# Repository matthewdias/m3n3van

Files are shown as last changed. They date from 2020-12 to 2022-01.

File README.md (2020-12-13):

# m3n3van
 
- The rev1 pcb supports a lot of different layouts. This was mostly an exercise for me and a way to make some unique bottom rows available that wouldn't exist otherwise. As a result it has a few issues, a missing switch, and lots of conflicts with screw holes, necessitating switch rotation.

- The rev2 pcb is a return to the original idea of simply a minivan with 2x3u split space.

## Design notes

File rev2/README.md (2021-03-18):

## Layout

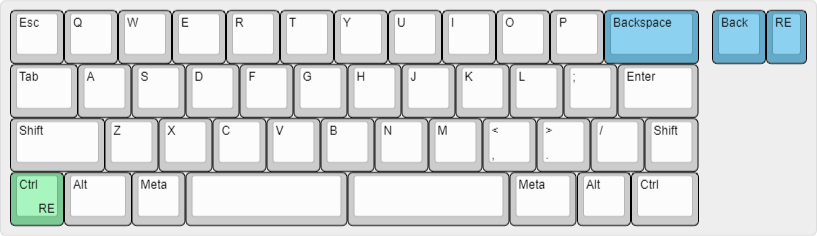
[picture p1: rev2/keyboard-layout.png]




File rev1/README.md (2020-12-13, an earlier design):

## Layout Options

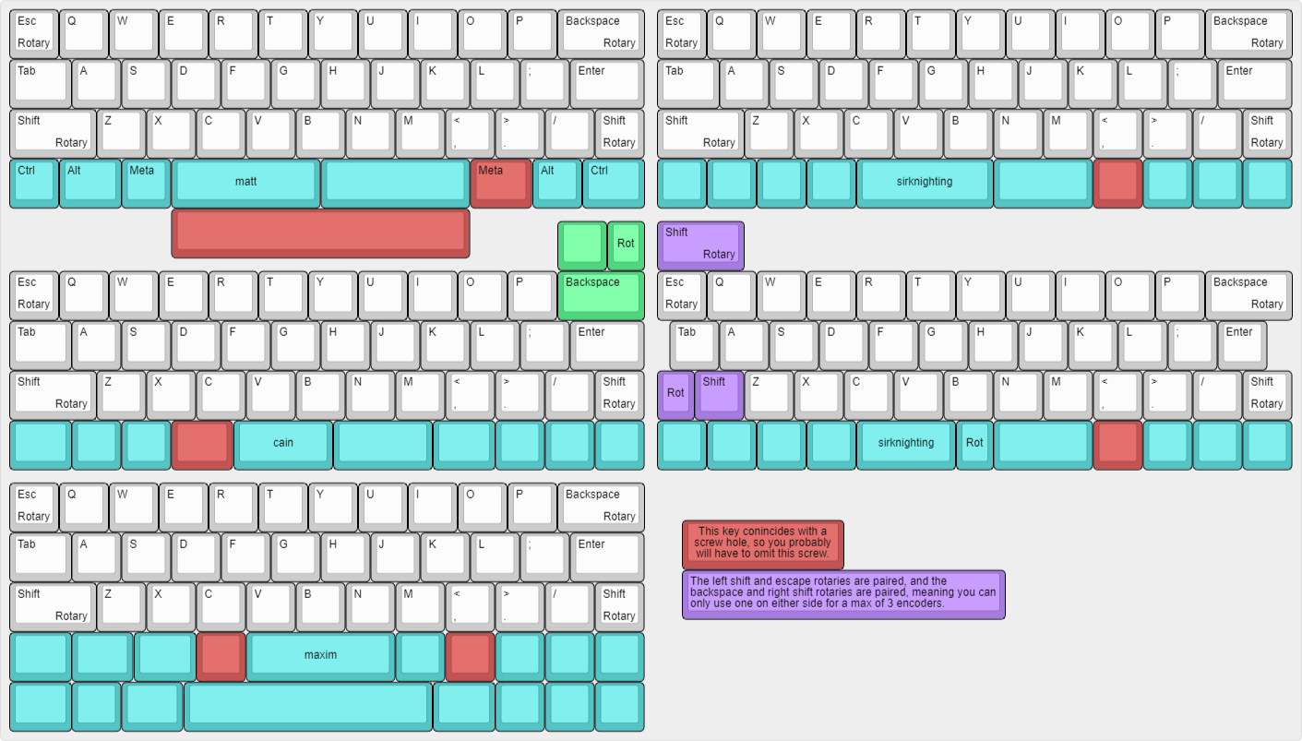
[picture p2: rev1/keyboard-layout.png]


Configure firmware at https://qmk.thevankeyboards.com/




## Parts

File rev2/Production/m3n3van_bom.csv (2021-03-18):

Designator | Quantity | Value | Footprint | LCSC Part #
C1, | 1 | 1uF | 0603 | C15849
C4, C3, C2, C5, C6, | 5 | 0.1uF | 0603 | C14663
C7, | 1 | 10uF | 0603 | C19702
D_1, D_2, D_3, D_4, D_5, D_6, D_7, D_8, D_9, D_10, D_11, D_12, D_13, D_14, D_15, D_16, D_17, D_18, D_19, D_20, D_21, D_22, D_23, D_24, D_25, D_26, D_27, D_28, D_29, D_30, D_31, D_32, D_33, D_34, D_35, D_36, D_37, D_38, D_39, D_40, D_41, D_42, D_43, D_44, D_45, | 45 | D | SOD-123 | C64898
F1, | 1 | 500mA | 1206 | C70076
R2, R3, | 2 | 5.1k | 0603 | C23186
R5, R4, | 2 | 22 | 0603 | C23345
R6, R1, | 2 | 10k | 0603 | C25804
SW1, | 1 | SW_Push | SMD | C561519
U1, | 1 | SRV05-4 | SOT-23-6 | C558454
U2, | 1 | AVR | 44-TQFP (10x10) | C44854
Y1, | 1 | 16MHz | SMD | C341521
USB1, | 1 | HRO-TYPE-C-31-M-12 | 8.94*7.3mm | C165948

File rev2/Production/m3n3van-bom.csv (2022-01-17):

Designator | Quantity | Value | Footprint | LCSC Part #
C1, | 1 | 1uF | 0603 | C15849
C2, C3, C4, C5, C6, | 5 | 0.1uF | 0603 | C14663
C7, | 1 | 10uF | 0603 | C19702
C8, C9, | 2 | 22pF | 0603 | C1653
D_1, D_2, D_3, D_4, D_5, D_6, D_7, D_8, D_9, D_10, D_11, D_12, D_13, D_14, D_15, D_16, D_17, D_18, D_19, D_20, D_21, D_22, D_23, D_24, D_25, D_26, D_27, D_28, D_29, D_30, D_31, D_32, D_33, D_34, D_35, D_36, D_37, D_38, D_39, D_40, D_41, D_42, D_43, D_44, D_45, | 45 | D | SOD-123 | C64898
F1, | 1 | 500mA | 1206 | C70076
R1, R6, | 2 | 10k | 0603 | C25804
R2, R3, | 2 | 5.1k | 0603 | C23186
R4, R5, | 2 | 22 | 0603 | C23345
SW1, | 1 | SW_Push | SMD | C561519
U1, | 1 | SRV05-4 | SOT-23-6 | C558454
U3, | 1 | ATmega32U4-MU | QFN-44 | C45874
USB1, | 1 | HRO-TYPE-C-31-M-12 | HRO-TYPE-C-31-M-12 | C165948
Y1, | 1 | 16MHz | 3225 | C13738

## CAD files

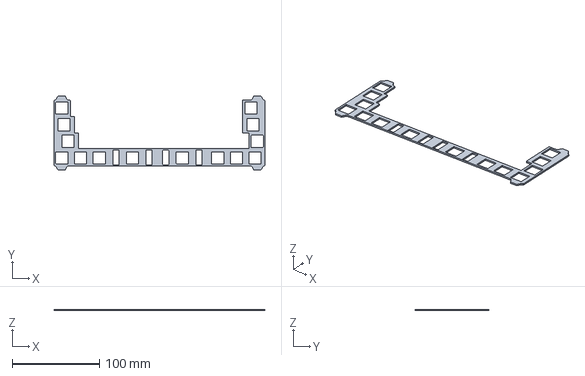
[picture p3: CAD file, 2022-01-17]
rev2/Plates/campsite/campsite-half.step
241.8 x 85.2 x 1.60 mm

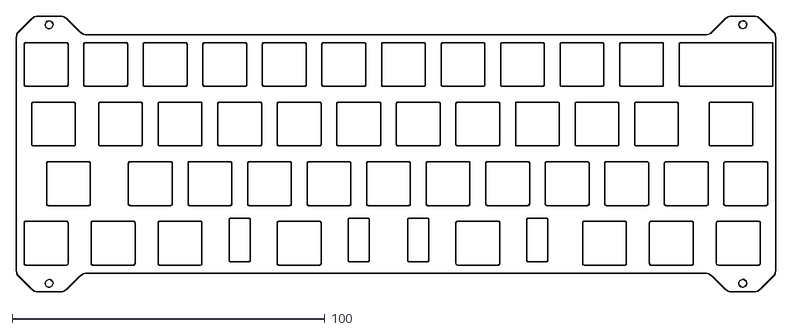
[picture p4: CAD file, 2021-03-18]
rev2/Plates/coriander/coriander.dxf
242.9 x 88.2

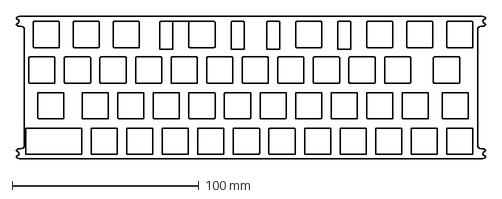
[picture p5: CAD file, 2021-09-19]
rev2/Plates/hull/hull.dxf
251.3 x 76.2 mm

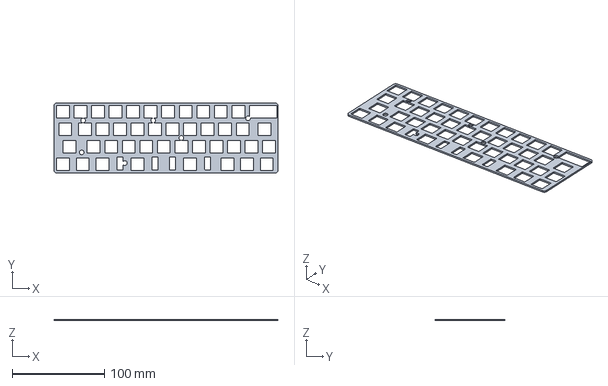
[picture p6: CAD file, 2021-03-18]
rev2/Plates/minivan/minivan.step
243.4 x 76.2 x 1.60 mm

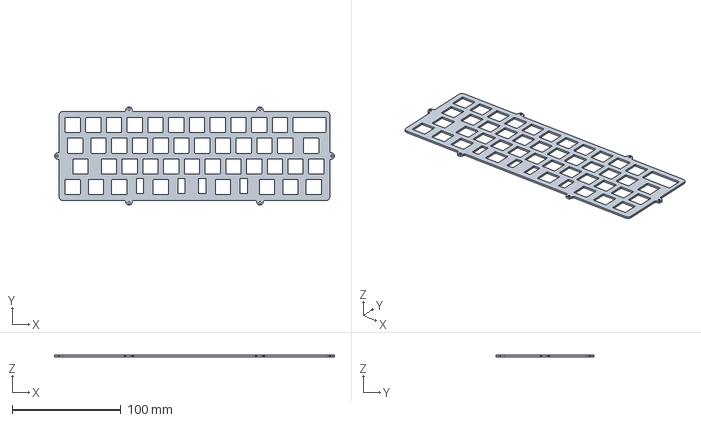
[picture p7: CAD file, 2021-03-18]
rev2/Plates/p3d-topmount/p3d-topmount.step
257.1 x 90.4 x 1.60 mm

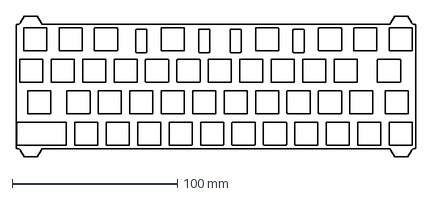
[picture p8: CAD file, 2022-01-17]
rev2/Plates/campsite/campsite-m3n3van.dxf
241.8 x 85.2 mm

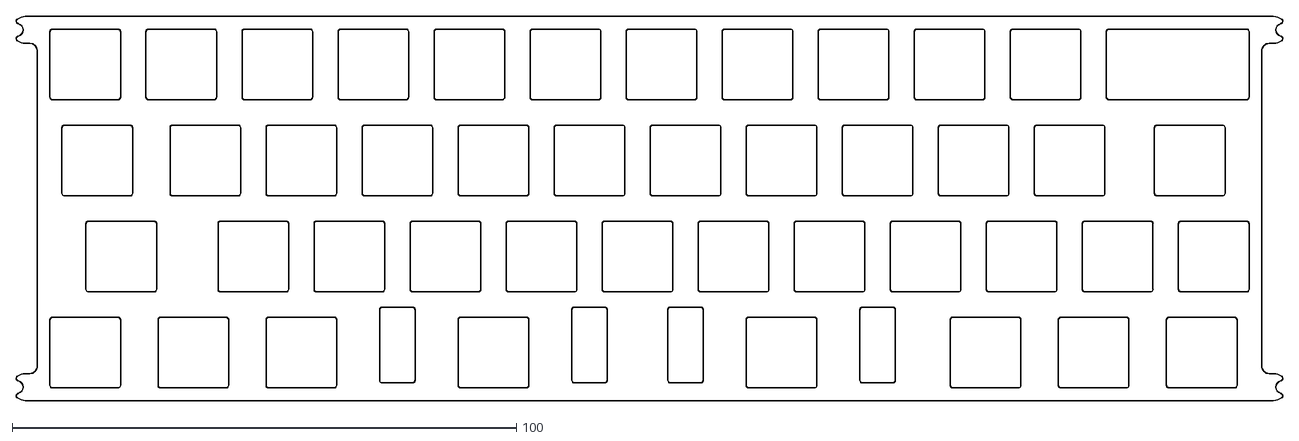
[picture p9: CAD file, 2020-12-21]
rev2/Plates/hull/hull-Edge_Cuts.dxf
251.3 x 76.2

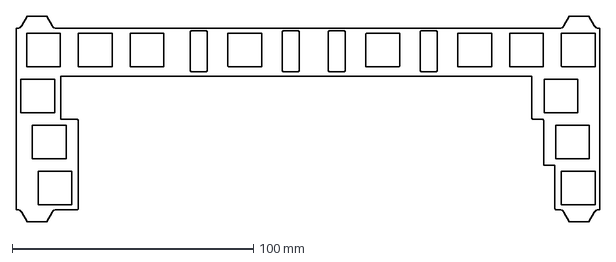
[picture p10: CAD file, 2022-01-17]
rev2/Plates/campsite/campsite-half-m3n3van.dxf
241.8 x 85.2 mm

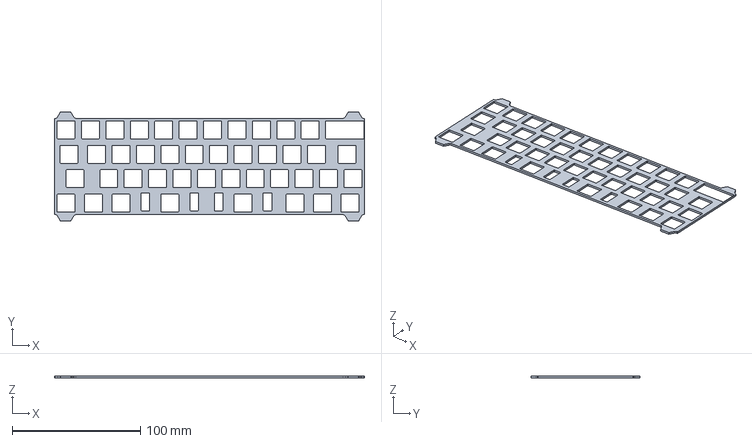
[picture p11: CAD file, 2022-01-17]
rev2/Plates/campsite/campsite.step
241.8 x 85.2 x 1.60 mm

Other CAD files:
rev2/Plates/minivan/minivan.dxf
rev2/Plates/p3d-topmount/p3d-topmount.dxf

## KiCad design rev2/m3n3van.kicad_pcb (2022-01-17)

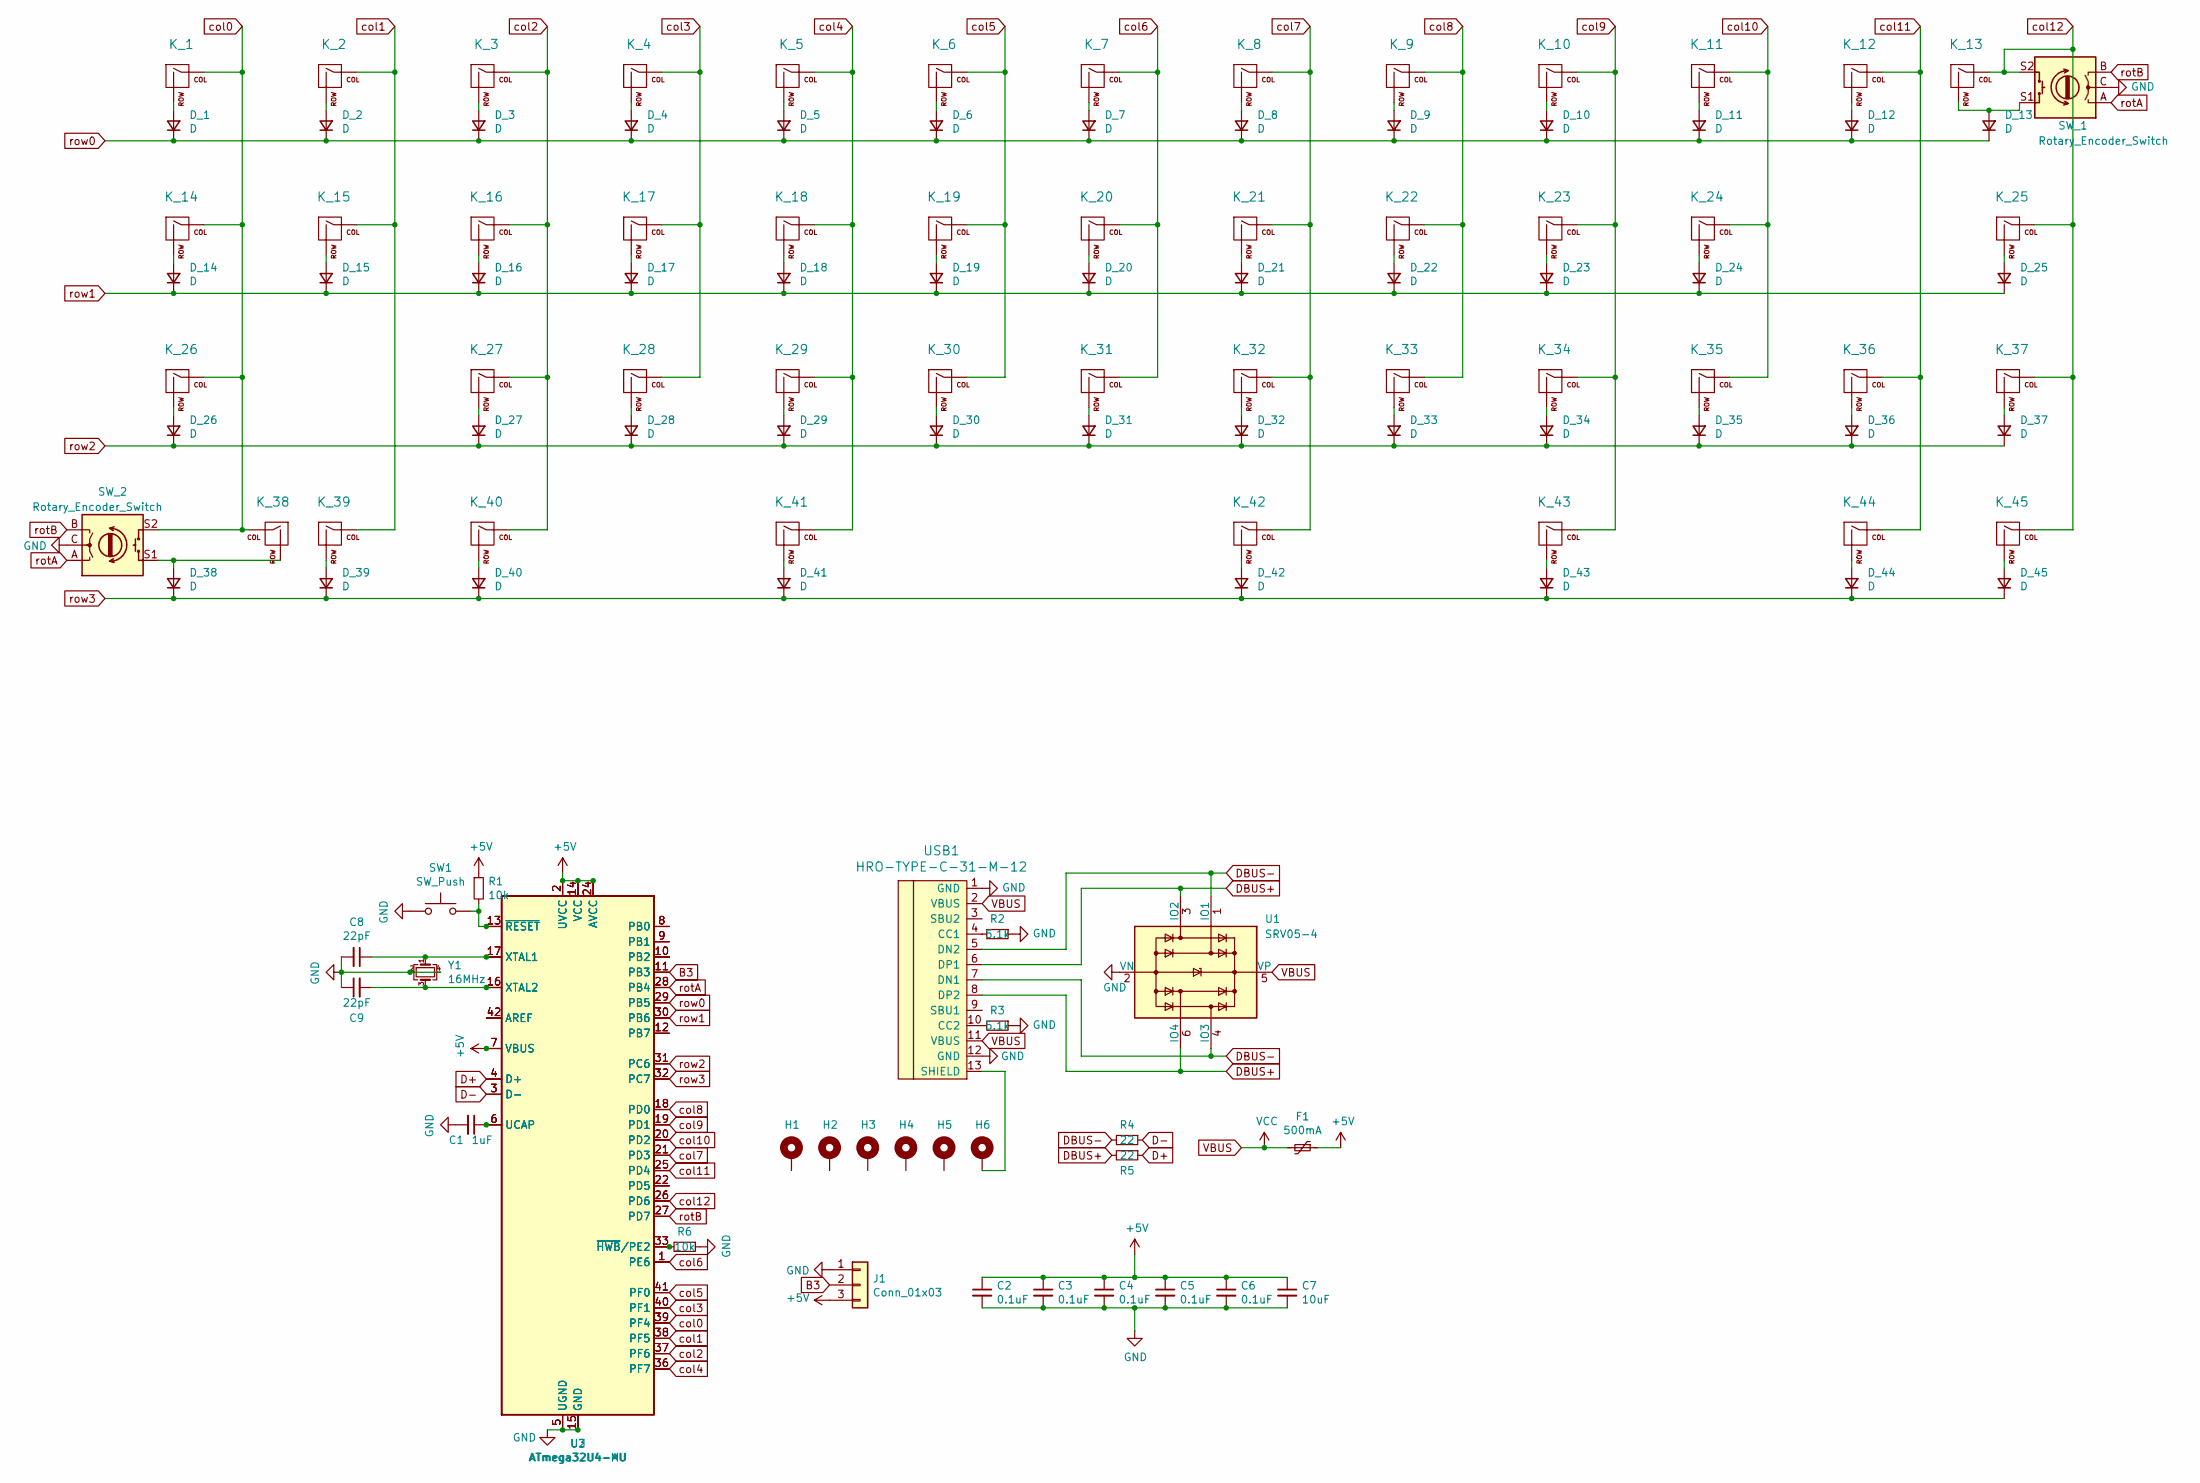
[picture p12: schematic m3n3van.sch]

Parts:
C1: 1uF; C_0603_1608Metric
C2, C3, C4, C5, C6: 0.1uF; C_0603_1608Metric
C7: 10uF; C_0603_1608Metric
C8, C9: 22pF; C_0603_1608Metric
D_1, D_2, D_3, D_4, D_5, D_6, D_7, D_8, D_9, D_10, D_11, D_12, D_13, D_14, D_15, D_16, D_17, D_18, D_19, D_20, D_21, D_22, D_23, D_24, D_25, D_26, D_27, D_28, D_29, D_30, D_31, D_32, D_33, D_34, D_35, D_36, D_37, D_38, D_39, D_40, D_41, D_42, D_43, D_44, D_45: D; D_SOD-123
F1: 500mA; Fuse_1206_3216Metric
H1, H2, H3, H4, H5, H6: MountingHole_Pad; MountingHole_2.2mm_M2_Pad
J1: Conn_01x03; PinHeader_1x03_P2.54mm_Vertical
K_1, K_2, K_3, K_4, K_5, K_6, K_7, K_8, K_9, K_10, K_11, K_12, K_15, K_16, K_17, K_18, K_19, K_20, K_21, K_22, K_23, K_24, K_27, K_28, K_29, K_30, K_31, K_32, K_33, K_34, K_35, K_36, K_37, K_38, K_40, K_44: KEYSW; MXOnly-1U-NoLED
K_13, K_26: KEYSW; MXOnly-1.75U-NoLED
K_14, K_39, K_43, K_45: KEYSW; MXOnly-1.25U-NoLED
K_25: KEYSW; MXOnly-1.5U-NoLED
K_41, K_42: KEYSW; MXOnly-3U-ReversedStabilizers-NoLED
R1, R6: 10k; R_0603_1608Metric
R2, R3: 5.1k; R_0603_1608Metric
R4, R5: 22; R_0603_1608Metric
SW1: SW_Push; SW_Push_SPST_NO_Alps_SKRK
SW_1, SW_2: Rotary_Encoder_Switch; RotaryEncoder_Alps_EC11E-Switch_Vertical_H20mm
U1: SRV05-4; SOT-23-6
U2: ATmega32U4-AU; TQFP-44_10x10mm_P0.8mm
U3: ATmega32U4-MU; QFN-44-1EP_7x7mm_P0.5mm_EP5.2x5.2mm
USB1: HRO-TYPE-C-31-M-12; HRO-TYPE-C-31-M-12-Assembly
Y1: 16MHz; Crystal_SMD_3225-4Pin_3.2x2.5mm

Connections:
+5V: C2.1, C3.1, C4.1, C5.1, C6.1, C7.1, F1.1, J1.3, R1.1, U2.2 (UVCC), U2.7 (VBUS), U2.14 (VCC), U2.24 (AVCC), U2.34 (VCC), U2.44 (AVCC), U3.2 (UVCC), U3.7 (VBUS), U3.14 (VCC), U3.24 (AVCC), U3.34 (VCC), U3.44 (AVCC)
B3: J1.2, U2.11 (PB3), U3.11 (PB3)
D+: R5.1, U2.4 (D+), U3.4 (D+)
D-: R4.1, U2.3 (D-), U3.3 (D-)
DBUS+: R5.2, U1.3 (IO2), U1.6 (IO4), USB1.6 (DP1), USB1.8 (DP2)
DBUS-: R4.2, U1.1 (IO1), U1.4 (IO3), USB1.5 (DN2), USB1.7 (DN1)
GND: C1.2, C2.2, C3.2, C4.2, C5.2, C6.2, C7.2, C8.2, C9.1, J1.1, R2.1, R3.1, R6.1, SW1.1, SW_1.C, SW_2.C, U1.2 (VN), U2.5 (UGND), U2.15 (GND), U2.23 (GND), U2.35 (GND), U2.43 (GND), U3.5 (UGND), U3.15 (GND), U3.23 (GND), U3.35 (GND), U3.43 (GND), U3.45 (GND), USB1.1 (GND), USB1.12 (GND), Y1.2, Y1.4
unnamed: C1.1, U2.6 (UCAP), U3.6 (UCAP)
unnamed: C8.1, U2.17 (XTAL1), U3.17 (XTAL1), Y1.1
unnamed: C9.2, U2.16 (XTAL2), U3.16 (XTAL2), Y1.3
unnamed: D_1.2 (A), K_1.2 (ROW)
unnamed: D_2.2 (A), K_2.2 (ROW)
unnamed: D_3.2 (A), K_3.2 (ROW)
unnamed: D_4.2 (A), K_4.2 (ROW)
unnamed: D_5.2 (A), K_5.2 (ROW)
unnamed: D_6.2 (A), K_6.2 (ROW)
unnamed: D_7.2 (A), K_7.2 (ROW)
unnamed: D_8.2 (A), K_8.2 (ROW)
unnamed: D_9.2 (A), K_9.2 (ROW)
unnamed: D_10.2 (A), K_10.2 (ROW)
unnamed: D_11.2 (A), K_11.2 (ROW)
unnamed: D_12.2 (A), K_12.2 (ROW)
unnamed: D_13.2 (A), K_13.2 (ROW), SW_1.S1
unnamed: D_14.2 (A), K_14.2 (ROW)
unnamed: D_15.2 (A), K_15.2 (ROW)
unnamed: D_16.2 (A), K_16.2 (ROW)
unnamed: D_17.2 (A), K_17.2 (ROW)
unnamed: D_18.2 (A), K_18.2 (ROW)
unnamed: D_19.2 (A), K_19.2 (ROW)
unnamed: D_20.2 (A), K_20.2 (ROW)
unnamed: D_21.2 (A), K_21.2 (ROW)
unnamed: D_22.2 (A), K_22.2 (ROW)
unnamed: D_23.2 (A), K_23.2 (ROW)
unnamed: D_24.2 (A), K_24.2 (ROW)
unnamed: D_25.2 (A), K_25.2 (ROW)
unnamed: D_26.2 (A), K_26.2 (ROW)
unnamed: D_27.2 (A), K_27.2 (ROW)
unnamed: D_28.2 (A), K_28.2 (ROW)
unnamed: D_29.2 (A), K_29.2 (ROW)
unnamed: D_30.2 (A), K_30.2 (ROW)
unnamed: D_31.2 (A), K_31.2 (ROW)
unnamed: D_32.2 (A), K_32.2 (ROW)
unnamed: D_33.2 (A), K_33.2 (ROW)
unnamed: D_34.2 (A), K_34.2 (ROW)
unnamed: D_35.2 (A), K_35.2 (ROW)
unnamed: D_36.2 (A), K_36.2 (ROW)
unnamed: D_37.2 (A), K_37.2 (ROW)
unnamed: D_38.2 (A), K_38.2 (ROW), SW_2.S1
unnamed: D_39.2 (A), K_39.2 (ROW)
unnamed: D_40.2 (A), K_40.2 (ROW)
unnamed: D_41.2 (A), K_41.2 (ROW)
unnamed: D_42.2 (A), K_42.2 (ROW)
unnamed: D_43.2 (A), K_43.2 (ROW)
unnamed: D_44.2 (A), K_44.2 (ROW)
unnamed: D_45.2 (A), K_45.2 (ROW)
unnamed: H6.1, USB1.13 (SHIELD)
unnamed: R1.2, SW1.2, U2.13 (~RESET), U3.13 (~RESET)
unnamed: R2.2, USB1.4 (CC1)
unnamed: R3.2, USB1.10 (CC2)
unnamed: R6.2, U2.33 (~HWB~/PE2), U3.33 (~HWB~/PE2)
unnamed: U2.8 (PB0), U3.8 (PB0)
unnamed: U2.9 (PB1), U3.9 (PB1)
unnamed: U2.10 (PB2), U3.10 (PB2)
unnamed: U2.12 (PB7), U3.12 (PB7)
unnamed: U2.22 (PD5), U3.22 (PD5)
unnamed: U2.42 (AREF), U3.42 (AREF)
VBUS: F1.2, U1.5 (VP), USB1.2 (VBUS), USB1.11 (VBUS)
col0: K_1.1 (COL), K_14.1 (COL), K_26.1 (COL), K_38.1 (COL), SW_2.S2, U2.39 (PF4), U3.39 (PF4)
col1: K_2.1 (COL), K_15.1 (COL), K_39.1 (COL), U2.38 (PF5), U3.38 (PF5)
col2: K_3.1 (COL), K_16.1 (COL), K_27.1 (COL), K_40.1 (COL), U2.37 (PF6), U3.37 (PF6)
col3: K_4.1 (COL), K_17.1 (COL), K_28.1 (COL), U2.40 (PF1), U3.40 (PF1)
col4: K_5.1 (COL), K_18.1 (COL), K_29.1 (COL), K_41.1 (COL), U2.36 (PF7), U3.36 (PF7)
col5: K_6.1 (COL), K_19.1 (COL), K_30.1 (COL), U2.41 (PF0), U3.41 (PF0)
col6: K_7.1 (COL), K_20.1 (COL), K_31.1 (COL), U2.1 (PE6), U3.1 (PE6)
col7: K_8.1 (COL), K_21.1 (COL), K_32.1 (COL), K_42.1 (COL), U2.21 (PD3), U3.21 (PD3)
col8: K_9.1 (COL), K_22.1 (COL), K_33.1 (COL), U2.18 (PD0), U3.18 (PD0)
col9: K_10.1 (COL), K_23.1 (COL), K_34.1 (COL), K_43.1 (COL), U2.19 (PD1), U3.19 (PD1)
col10: K_11.1 (COL), K_24.1 (COL), K_35.1 (COL), U2.20 (PD2), U3.20 (PD2)
col11: K_12.1 (COL), K_36.1 (COL), K_44.1 (COL), U2.25 (PD4), U3.25 (PD4)
col12: K_13.1 (COL), K_25.1 (COL), K_37.1 (COL), K_45.1 (COL), SW_1.S2, U2.26 (PD6), U3.26 (PD6)
rotA: SW_1.A, SW_2.A, U2.28 (PB4), U3.28 (PB4)
rotB: SW_1.B, SW_2.B, U2.27 (PD7), U3.27 (PD7)
row0: D_1.1 (K), D_2.1 (K), D_3.1 (K), D_4.1 (K), D_5.1 (K), D_6.1 (K), D_7.1 (K), D_8.1 (K), D_9.1 (K), D_10.1 (K), D_11.1 (K), D_12.1 (K), D_13.1 (K), U2.29 (PB5), U3.29 (PB5)
row1: D_14.1 (K), D_15.1 (K), D_16.1 (K), D_17.1 (K), D_18.1 (K), D_19.1 (K), D_20.1 (K), D_21.1 (K), D_22.1 (K), D_23.1 (K), D_24.1 (K), D_25.1 (K), U2.30 (PB6), U3.30 (PB6)
row2: D_26.1 (K), D_27.1 (K), D_28.1 (K), D_29.1 (K), D_30.1 (K), D_31.1 (K), D_32.1 (K), D_33.1 (K), D_34.1 (K), D_35.1 (K), D_36.1 (K), D_37.1 (K), U2.31 (PC6), U3.31 (PC6)
row3: D_38.1 (K), D_39.1 (K), D_40.1 (K), D_41.1 (K), D_42.1 (K), D_43.1 (K), D_44.1 (K), D_45.1 (K), U2.32 (PC7), U3.32 (PC7)

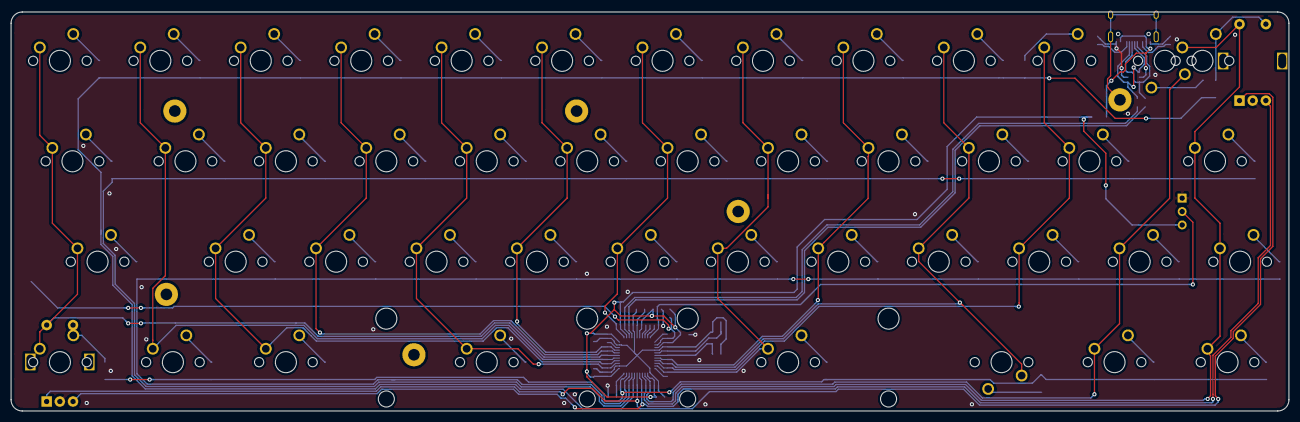
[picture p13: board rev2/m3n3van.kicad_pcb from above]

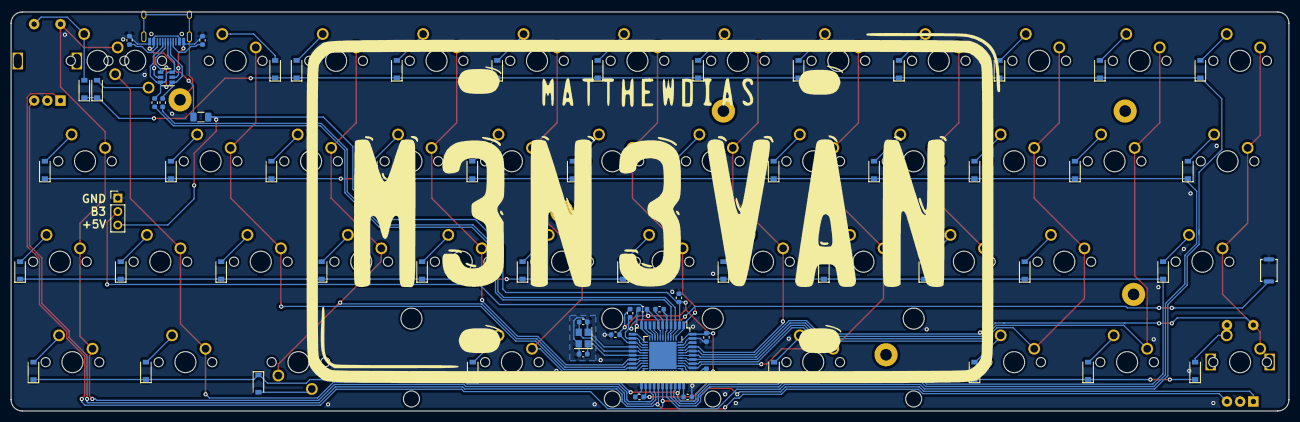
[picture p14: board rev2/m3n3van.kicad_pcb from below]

Board: 2 copper layers, 242.4 x 75.7 mm, 121 parts (68 on the bottom side), 86 nets.

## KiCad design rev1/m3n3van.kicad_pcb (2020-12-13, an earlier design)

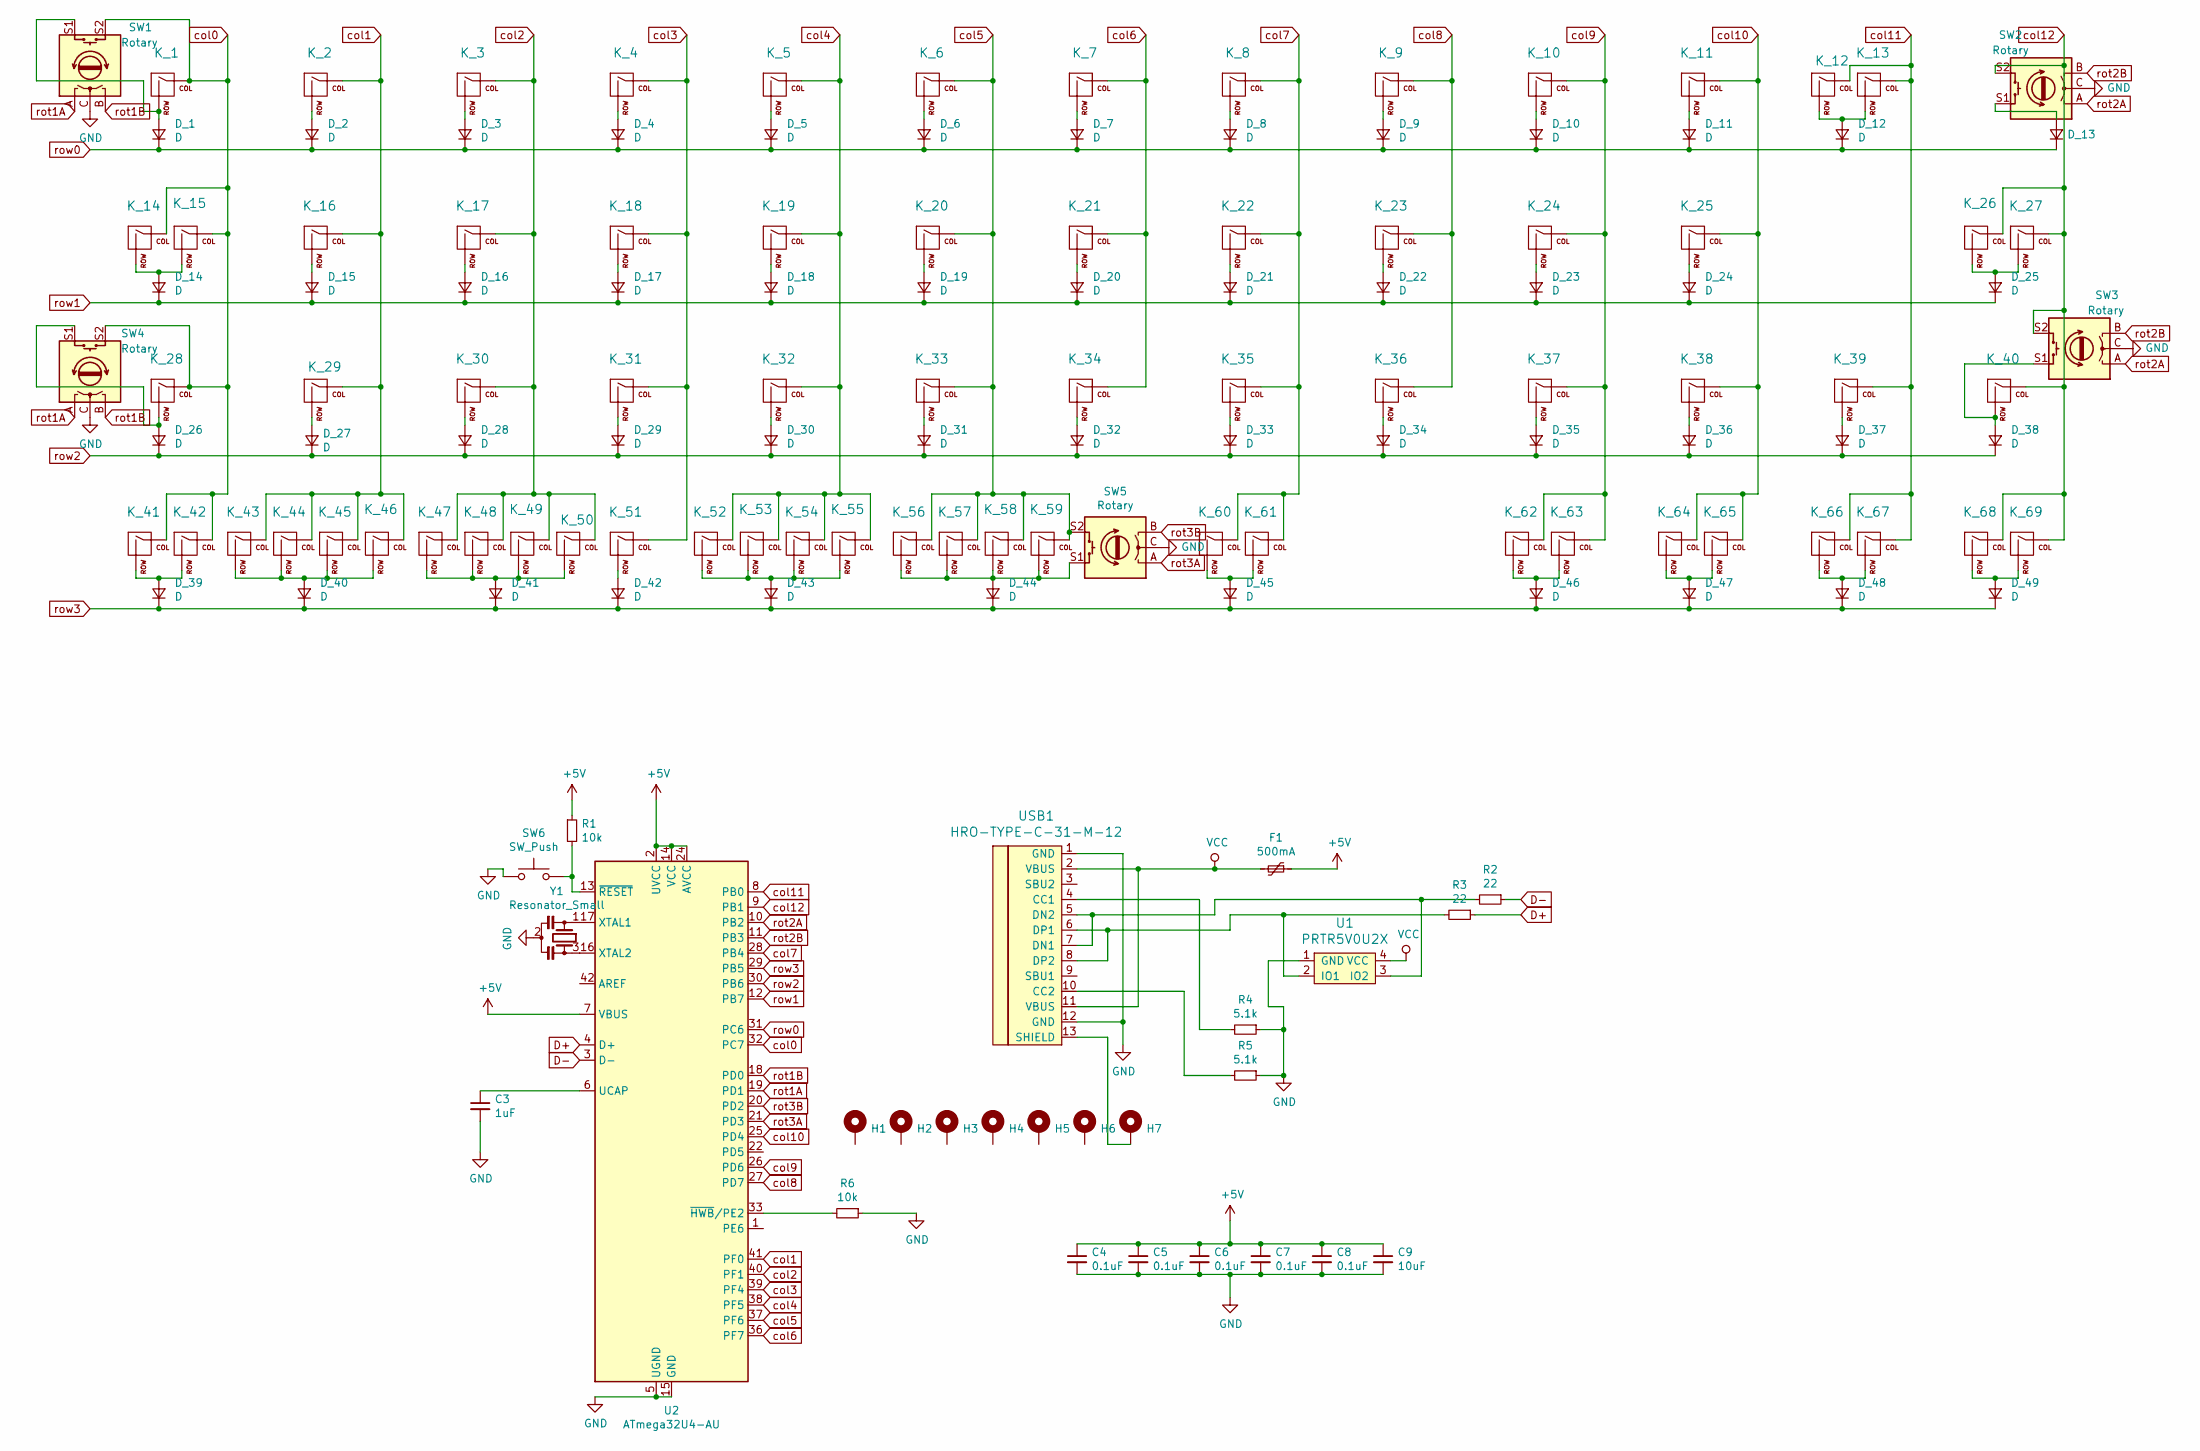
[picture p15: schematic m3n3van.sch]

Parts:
C3: 1uF; C_0805_2012Metric
C4, C5, C6, C7, C8: 0.1uF; C_0805_2012Metric
C9: 10uF; C_0805_2012Metric
D_1, D_2, D_3, D_4, D_5, D_6, D_7, D_8, D_9, D_10, D_11, D_12, D_13, D_14, D_15, D_16, D_17, D_18, D_19, D_20, D_21, D_22, D_23, D_24, D_25, D_26, D_27, D_28, D_29, D_30, D_31, D_32, D_33, D_34, D_35, D_36, D_37, D_38, D_39, D_40, D_41, D_42, D_43, D_44, D_45, D_46, D_47, D_48, D_49: D; D_SOD-123
F1: 500mA; Fuse_1206_3216Metric
H1, H2, H3, H4, H5, H6, H7: MountingHole_Pad; MountingHole_2.2mm_M2_Pad
K_1, K_2, K_3, K_4, K_5, K_6, K_7, K_8, K_9, K_10, K_11, K_12, K_15, K_16, K_17, K_18, K_19, K_20, K_21, K_22, K_23, K_24, K_25, K_26, K_29, K_30, K_31, K_32, K_33, K_34, K_35, K_36, K_37, K_38, K_39, K_40, K_41, K_43, K_45, K_47, K_48, K_51, K_53, K_63, K_65, K_66, K_67, K_69: KEYSW; MXOnly-1U-NoLED
K_13, K_28: KEYSW; MXOnly-1.75U-NoLED
K_14, K_42, K_44, K_46, K_49, K_50, K_52, K_62, K_64, K_68: KEYSW; MXOnly-1.25U-NoLED
K_27: KEYSW; MXOnly-1.5U-NoLED
K_54: KEYSW; MXOnly-3U-ReversedStabilizers-NoLED
K_55, K_57, K_60: KEYSW; MXOnly-2U-NoStab-NoLED
K_56: KEYSW; MXOnly-2.75U-ReversedStabilizers-NoLED
K_58: KEYSW; MXOnly-6U-Centered-3U-ReversedStabilizers-NoLED
K_59: KEYSW; MXOnly-5U-ReversedStabilizers-NoLED
K_61: KEYSW; MXOnly-3U-2U-ReversedStabilizers-NoLED
R1, R6: 10k; R_0805_2012Metric
R2, R3: 22; R_0805_2012Metric
R4, R5: 5.1k; R_0805_2012Metric
SW1, SW2, SW3, SW4, SW5: Rotary; RotaryEncoder_Alps_EC11E-Switch_Vertical_H20mm
SW6: SW_Push; SW_Push_1P1T_NO_CK_KMR2
U1: PRTR5V0U2X; SOT143B
U2: ATmega32U4-AU; TQFP-44_10x10mm_P0.8mm
USB1: HRO-TYPE-C-31-M-12; HRO-TYPE-C-31-M-12-Assembly
Y1: Resonator_Small; Resonator_SMD_muRata_CSTxExxV-3Pin_3.0x1.1mm_HandSoldering

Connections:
+5V: C4.1, C5.1, C6.1, C7.1, C8.1, C9.1, F1.1, R1.1, U2.2 (UVCC), U2.7 (VBUS), U2.14 (VCC), U2.24 (AVCC), U2.34 (VCC), U2.44 (AVCC)
D+: R3.1, U2.4 (D+)
D-: R2.1, U2.3 (D-)
GND: C3.2, C4.2, C5.2, C6.2, C7.2, C8.2, C9.2, R4.1, R5.1, R6.1, SW1.C, SW2.C, SW3.C, SW4.C, SW5.C, SW6.1, U1.1 (GND), U2.5 (UGND), U2.15 (GND), U2.23 (GND), U2.35 (GND), U2.43 (GND), USB1.1 (GND), USB1.12 (GND), Y1.2
unnamed: C3.1, U2.6 (UCAP)
unnamed: D_1.2 (A), K_1.2 (ROW), SW1.S1
unnamed: D_2.2 (A), K_2.2 (ROW)
unnamed: D_3.2 (A), K_3.2 (ROW)
unnamed: D_4.2 (A), K_4.2 (ROW)
unnamed: D_5.2 (A), K_5.2 (ROW)
unnamed: D_6.2 (A), K_6.2 (ROW)
unnamed: D_7.2 (A), K_7.2 (ROW)
unnamed: D_8.2 (A), K_8.2 (ROW)
unnamed: D_9.2 (A), K_9.2 (ROW)
unnamed: D_10.2 (A), K_10.2 (ROW)
unnamed: D_11.2 (A), K_11.2 (ROW)
unnamed: D_12.2 (A), K_12.2 (ROW), K_13.2 (ROW)
unnamed: D_13.2 (A), SW2.S1
unnamed: D_14.2 (A), K_14.2 (ROW), K_15.2 (ROW)
unnamed: D_15.2 (A), K_16.2 (ROW)
unnamed: D_16.2 (A), K_17.2 (ROW)
unnamed: D_17.2 (A), K_18.2 (ROW)
unnamed: D_18.2 (A), K_19.2 (ROW)
unnamed: D_19.2 (A), K_20.2 (ROW)
unnamed: D_20.2 (A), K_21.2 (ROW)
unnamed: D_21.2 (A), K_22.2 (ROW)
unnamed: D_22.2 (A), K_23.2 (ROW)
unnamed: D_23.2 (A), K_24.2 (ROW)
unnamed: D_24.2 (A), K_25.2 (ROW)
unnamed: D_25.2 (A), K_26.2 (ROW), K_27.2 (ROW)
unnamed: D_26.2 (A), K_28.2 (ROW), SW4.S1
unnamed: D_27.2 (A), K_29.2 (ROW)
unnamed: D_28.2 (A), K_30.2 (ROW)
unnamed: D_29.2 (A), K_31.2 (ROW)
unnamed: D_30.2 (A), K_32.2 (ROW)
unnamed: D_31.2 (A), K_33.2 (ROW)
unnamed: D_32.2 (A), K_34.2 (ROW)
unnamed: D_33.2 (A), K_35.2 (ROW)
unnamed: D_34.2 (A), K_36.2 (ROW)
unnamed: D_35.2 (A), K_37.2 (ROW)
unnamed: D_36.2 (A), K_38.2 (ROW)
unnamed: D_37.2 (A), K_39.2 (ROW)
unnamed: D_38.2 (A), K_40.2 (ROW), SW3.S1
unnamed: D_39.2 (A), K_41.2 (ROW), K_42.2 (ROW)
unnamed: D_40.2 (A), K_43.2 (ROW), K_44.2 (ROW), K_45.2 (ROW), K_46.2 (ROW)
unnamed: D_41.2 (A), K_47.2 (ROW), K_48.2 (ROW), K_49.2 (ROW), K_50.2 (ROW)
unnamed: D_42.2 (A), K_51.2 (ROW)
unnamed: D_43.2 (A), K_52.2 (ROW), K_53.2 (ROW), K_54.2 (ROW), K_55.2 (ROW)
unnamed: D_44.2 (A), K_56.2 (ROW), K_57.2 (ROW), K_58.2 (ROW), K_59.2 (ROW), SW5.S1
unnamed: D_45.2 (A), K_60.2 (ROW), K_61.2 (ROW)
unnamed: D_46.2 (A), K_62.2 (ROW), K_63.2 (ROW)
unnamed: D_47.2 (A), K_64.2 (ROW), K_65.2 (ROW)
unnamed: D_48.2 (A), K_66.2 (ROW), K_67.2 (ROW)
unnamed: D_49.2 (A), K_68.2 (ROW), K_69.2 (ROW)
unnamed: H7.1, USB1.13 (SHIELD)
unnamed: R1.2, SW6.2, U2.13 (~RESET)
unnamed: R2.2, U1.3 (IO2), USB1.5 (DN2), USB1.7 (DN1)
unnamed: R3.2, U1.2 (IO1), USB1.6 (DP1), USB1.8 (DP2)
unnamed: R4.2, USB1.4 (CC1)
unnamed: R5.2, USB1.10 (CC2)
unnamed: R6.2, U2.33 (~HWB~/PE2)
unnamed: U2.16 (XTAL2), Y1.3
unnamed: U2.17 (XTAL1), Y1.1
VCC: F1.2, U1.4 (VCC), USB1.2 (VBUS), USB1.11 (VBUS)
col0: K_1.1 (COL), K_14.1 (COL), K_15.1 (COL), K_28.1 (COL), K_41.1 (COL), K_42.1 (COL), SW1.S2, SW4.S2, U2.32 (PC7)
col1: K_2.1 (COL), K_16.1 (COL), K_29.1 (COL), K_43.1 (COL), K_44.1 (COL), K_45.1 (COL), K_46.1 (COL), U2.41 (PF0)
col2: K_3.1 (COL), K_17.1 (COL), K_30.1 (COL), K_47.1 (COL), K_48.1 (COL), K_49.1 (COL), K_50.1 (COL), U2.40 (PF1)
col3: K_4.1 (COL), K_18.1 (COL), K_31.1 (COL), K_51.1 (COL), U2.39 (PF4)
col4: K_5.1 (COL), K_19.1 (COL), K_32.1 (COL), K_52.1 (COL), K_53.1 (COL), K_54.1 (COL), K_55.1 (COL), U2.38 (PF5)
col5: K_6.1 (COL), K_20.1 (COL), K_33.1 (COL), K_56.1 (COL), K_57.1 (COL), K_58.1 (COL), K_59.1 (COL), SW5.S2, U2.37 (PF6)
col6: K_7.1 (COL), K_21.1 (COL), K_34.1 (COL), U2.36 (PF7)
col7: K_8.1 (COL), K_22.1 (COL), K_35.1 (COL), K_60.1 (COL), K_61.1 (COL), U2.28 (PB4)
col8: K_9.1 (COL), K_23.1 (COL), K_36.1 (COL), U2.27 (PD7)
col9: K_10.1 (COL), K_24.1 (COL), K_37.1 (COL), K_62.1 (COL), K_63.1 (COL), U2.26 (PD6)
col10: K_11.1 (COL), K_25.1 (COL), K_38.1 (COL), K_64.1 (COL), K_65.1 (COL), U2.25 (PD4)
col11: K_12.1 (COL), K_13.1 (COL), K_39.1 (COL), K_66.1 (COL), K_67.1 (COL), U2.8 (PB0)
col12: K_26.1 (COL), K_27.1 (COL), K_40.1 (COL), K_68.1 (COL), K_69.1 (COL), SW2.S2, SW3.S2, U2.9 (PB1)
rot1A: SW1.A, SW4.A, U2.19 (PD1)
rot1B: SW1.B, SW4.B, U2.18 (PD0)
rot2A: SW2.A, SW3.A, U2.10 (PB2)
rot2B: SW2.B, SW3.B, U2.11 (PB3)
rot3A: SW5.A, U2.21 (PD3)
rot3B: SW5.B, U2.20 (PD2)
row0: D_1.1 (K), D_2.1 (K), D_3.1 (K), D_4.1 (K), D_5.1 (K), D_6.1 (K), D_7.1 (K), D_8.1 (K), D_9.1 (K), D_10.1 (K), D_11.1 (K), D_12.1 (K), D_13.1 (K), U2.31 (PC6)
row1: D_14.1 (K), D_15.1 (K), D_16.1 (K), D_17.1 (K), D_18.1 (K), D_19.1 (K), D_20.1 (K), D_21.1 (K), D_22.1 (K), D_23.1 (K), D_24.1 (K), D_25.1 (K), U2.12 (PB7)
row2: D_26.1 (K), D_27.1 (K), D_28.1 (K), D_29.1 (K), D_30.1 (K), D_31.1 (K), D_32.1 (K), D_33.1 (K), D_34.1 (K), D_35.1 (K), D_36.1 (K), D_37.1 (K), D_38.1 (K), U2.30 (PB6)
row3: D_39.1 (K), D_40.1 (K), D_41.1 (K), D_42.1 (K), D_43.1 (K), D_44.1 (K), D_45.1 (K), D_46.1 (K), D_47.1 (K), D_48.1 (K), D_49.1 (K), U2.29 (PB5)

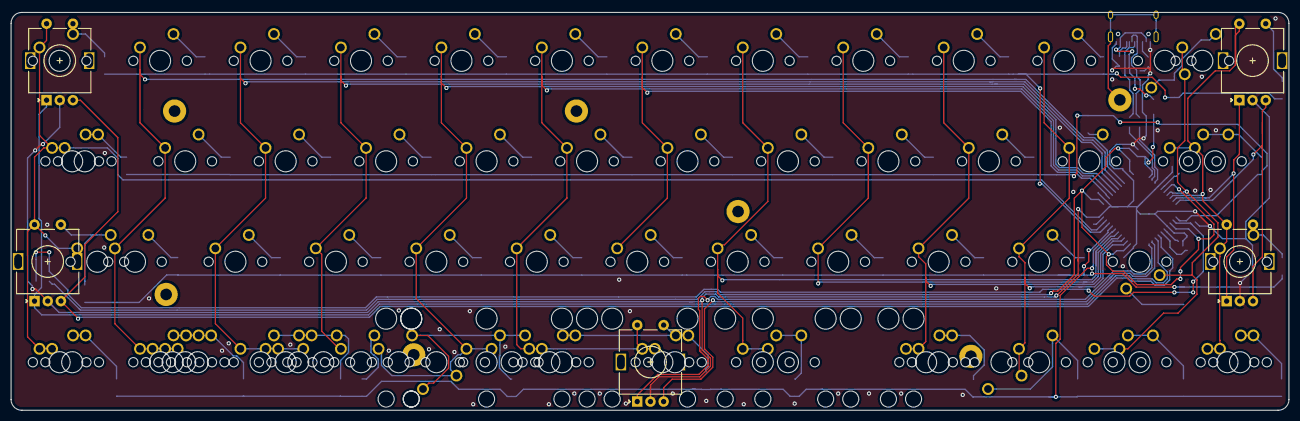
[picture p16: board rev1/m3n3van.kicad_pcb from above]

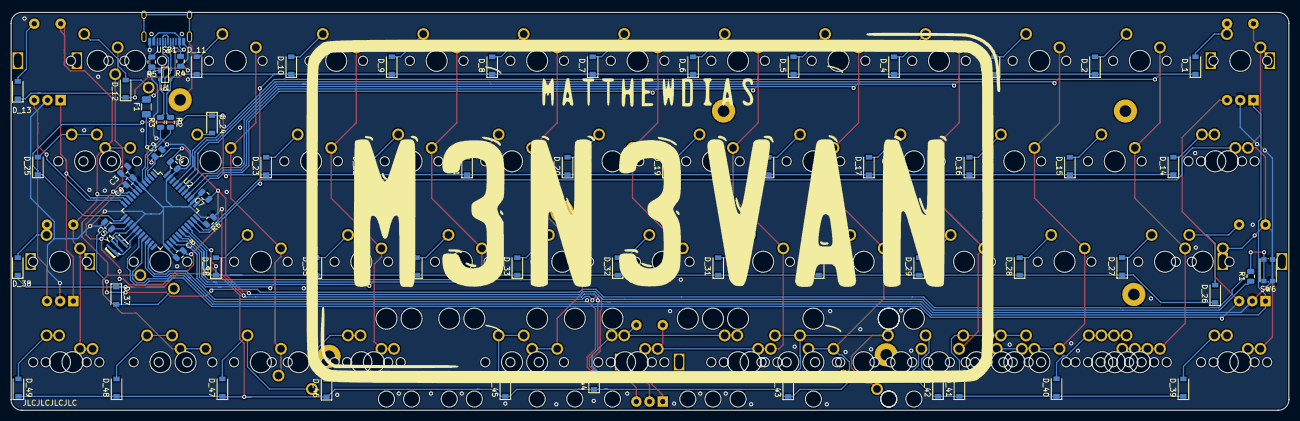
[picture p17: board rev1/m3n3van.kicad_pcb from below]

Board: 2 copper layers, 242.3 x 75.4 mm, 149 parts (68 on the bottom side), 87 nets.

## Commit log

2020-11-30 Add rev2 PCB
    [m3n3van.kicad_pcb, m3n3van.sch]
2020-11-30 Address review feedback
    [m3n3van.kicad_pcb]
2020-12-13 Add rev1 pcb
    [m3n3van-B_Cu.gbr, m3n3van-B_Mask.gbr, m3n3van-B_SilkS.gbr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]
2020-12-13 Update rev2 for production
    [m3n3van-B_Cu.gbr, m3n3van-B_Fab.gbr, m3n3van-B_Mask.gbr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]
2020-12-21 Add plate files
    [hull-Edge_Cuts.dxf, hull.kicad_pcb, hull.sch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]
2021-01-31 Add Coriander plate
    [coriander-Edge_Cuts.dxf, coriander.kicad_pcb, coriander.sch]
2021-03-18 Add second encoder, RGB header, switch to assembly resonator footprint
    [m3n3van.kicad_pcb, m3n3van.sch]
2021-03-18 Fix plate encoder cutouts
    [coriander-Edge_Cuts.dxf, coriander.dxf, coriander.kicad_pcb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]
2021-03-18 Update components, production files
    [m3n3van-B_Cu.gbr, m3n3van-B_Fab.gbr, m3n3van-B_Mask.gbr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]
2022-01-17 Add usb to rev1 production files
    [m3n3van-bom.csv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]
2022-01-17 Switch to crystal, add MU dual footprint
    [m3n3van-bom.csv, m3n3van.kicad_pcb, m3n3van.sch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]
2022-01-17 Add campsite plates
    [campsite-half-m3n3van.dxf, campsite-half.kicad_pcb, campsite-half.step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]
